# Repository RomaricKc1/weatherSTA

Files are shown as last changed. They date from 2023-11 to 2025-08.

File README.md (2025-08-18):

# weatherSTA

# Weather Station and Clock with ESP32, BME280, SCD40 and OpenWeather API

This project is a weather station and clock, that runs on an `ESP32` using the `Arduino` framework and `FreeRTOS`. It measures and displays indoor environmental data in real-time, as well as outdoor weather data through the OpenWeather API.

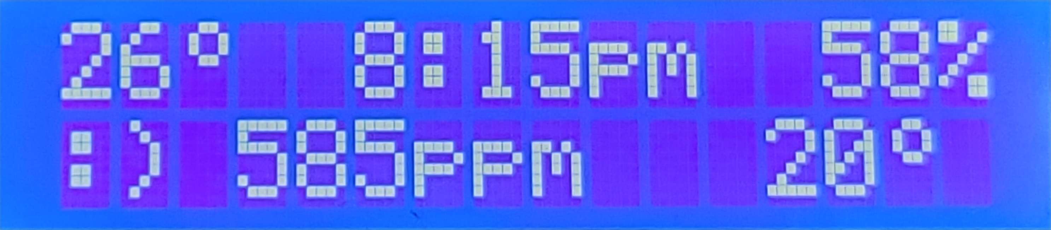
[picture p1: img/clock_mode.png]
Clock mode


Dashboard example            |  Enclosure: Box | Enclosure: Lid
:-------------------------:|:-------------------------:|-------------------------:
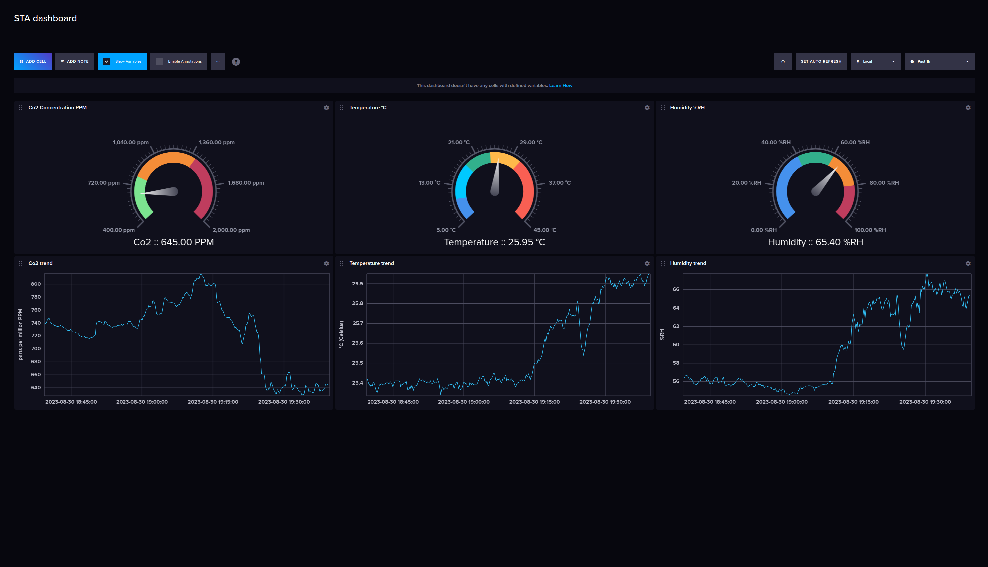
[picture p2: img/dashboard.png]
Dashboard
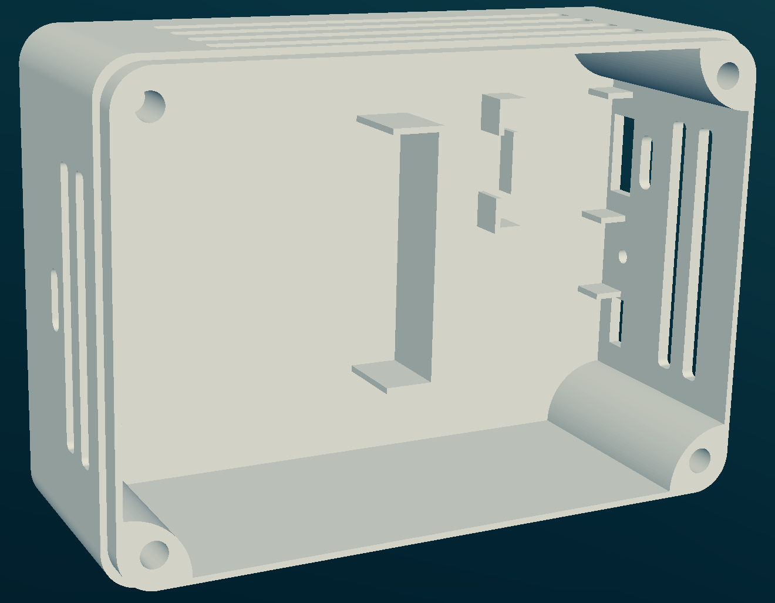
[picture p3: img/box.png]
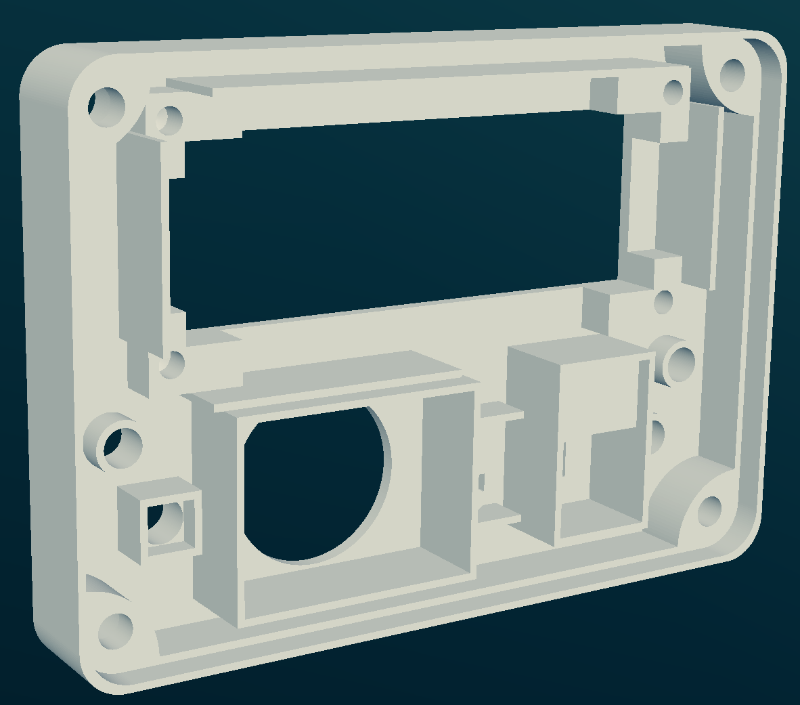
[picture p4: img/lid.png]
  |   |  

<details>
<summary>Click to view the results displayed on the browser</summary>

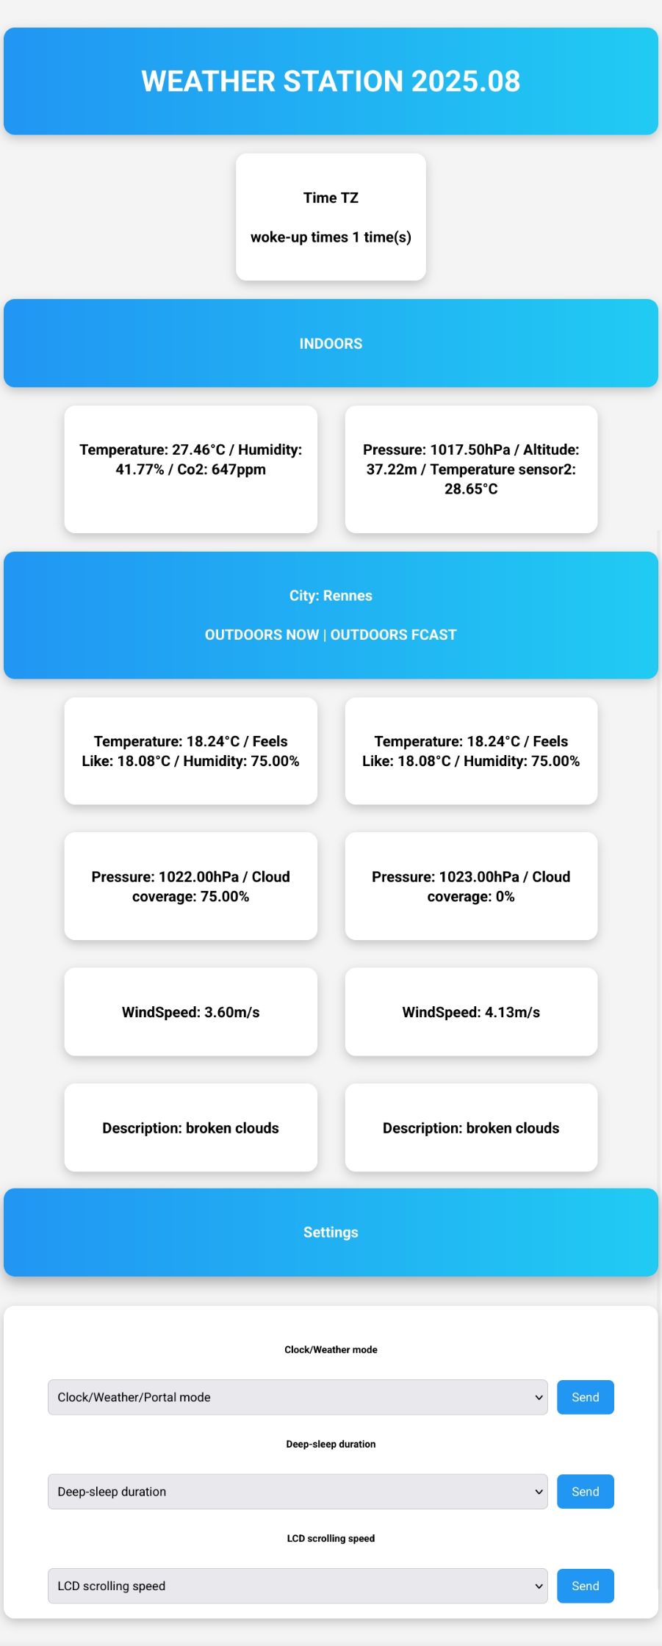
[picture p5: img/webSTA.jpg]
webview


</details>

## Getting Started

> [!IMPORTANT]
> Download the already compiled firmware(`.hex, .bin, the partitions.bin and the spiffs`) from the `release page` and flash it to your `ESP32`. 
>
> Alternatively, you can build it from source by yourself.
>
> Boot the ESP and connect to the created WIFI network `"STA esp"`. The default password (`P@55w0rd`) is in the `configs.hpp` header file.
>
> Connect the ESP to the desired WIFI network in the wifimanager portal, then reboot to validate the access point. After that, you'll have to reconnect to the portal in the `setup` page, to enter the required configuration parameters. After that, the esp will reboot and you'll be all set. `Voilà`.

### Build Steps
```bash
# build and upload file system
platformio run --target uploadfs -e esp32dev
# build and upload firmware
platformio run --target upload -e esp32dev 
```

> [!NOTE]
> You can access the web server via `http://weather_sta.local` or by looking up the ip addressed assigned to the esp32 and going to `http://[ip_addr]`
>
> Many of the configuration options can be modified in the `configs.hpp`. Such as timing related, `ntp` servers and `timezone` etc.
>
> Almost the essentials configs can be done dynamically. After the firmware has been built, you can use the wifi manager portal to set the value as you wish.

### OTA Updates
You can upload a new firmware through `WiFiManager` at `http://[ip_addr]/update`. You can enable the `on-demand` portal using the physical `button` connected to the `pin27`, and navigate to `Chg WLAN` and set it to `Yes`.

## Features

**Two Operating Modes**: The system operates in two distinct modes - Clock Mode (default) and Station Mode.
   - **Clock Mode**: Displays indoor environment data (temperature, humidity, CO2 concentration) and the current time. The time is fetched using the NTP protocol.
   - **Station Mode**: Cycles through displaying indoor data, current outdoor data from the OpenWeather API, and outdoor forecast data. After cycling, the system goes idle for a configurable duration, shuts down, and then restarts.

> [!NOTE]
> The system uses a PIR sensor to detect human presence and manage the LCD backlight, reducing power consumption. The PIR sensor's duration is configurable.
>
> The system connects to WiFi using WiFiManager with local webserver
>
> Three LEDs indicating rain (from current weather data), hot (indoor temperature above 24°C), and cold conditions.
>
> A buzzer provides hourly chimes, with a long chime at 12 am and pm. It stops making noise from 2 am to 6 am.
>
> InfluxDB integration: pushes every 10s data that can be visualized using the provided dashboard (see influx_dashboard)
> STL files for a 3D printable enclosure.

## Main Sensors

1. BME280 Sensor: Used for measuring indoor temperature, humidity, and pressure.
2. SCD40 Sensor: Used for measuring indoor CO2 concentration.

## Libraries Used

More in `platformio.ini` file.

## Wirings
| Module | Connection |
|---|---|
| LCD 16x2 |  I2C  |
| BME280 |  I2C  |
| SCD40  |  I2C  |
| LED cold  |  D19  |
| LED hot |  D18  |
| LED rain  |  D5  |
| BTN  |  D27  |
| Buzzer  |  D2  |
| PIR  |  D17  |

## MISC
WIFI connection lost: `LED cold` and `LED hot` blink for 5s.

### Config Menu: 
`CLOCK mode {ON/OFF}`, `LCD Speed 250-500(ms)`, `Sleep T 30-60(s)`, `Deep-sleep T 15-60(mins)`,`Am/PM {AM/PM}`, `Chg WLAN {ON/OFF}`

### TODO
- [ ] Outdoors air quality metrics
- [ ] Add target for other esp version

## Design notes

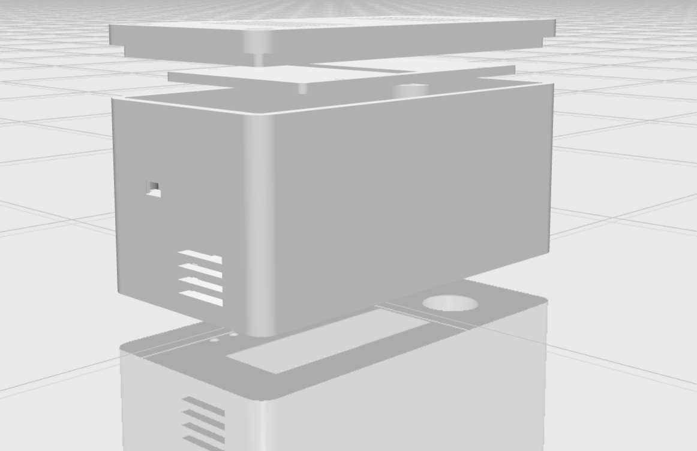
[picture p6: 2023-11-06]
img/enclosure.png

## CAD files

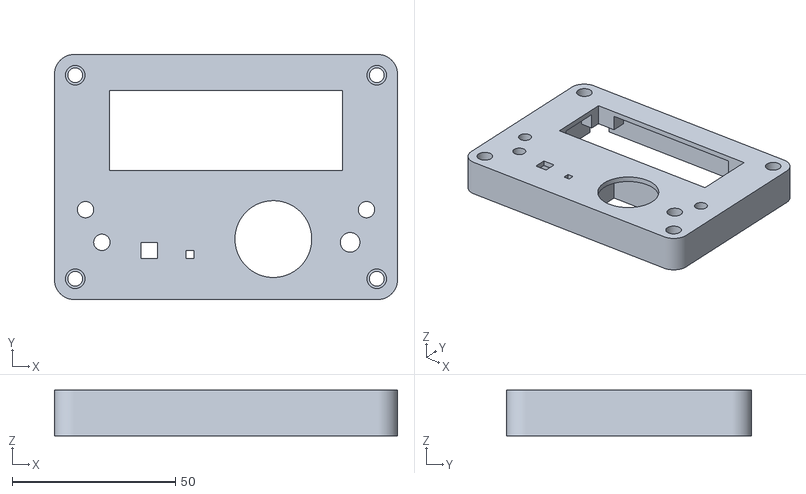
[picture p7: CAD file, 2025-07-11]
STL_file/Lid.stl
105.0 x 75.0 x 14.0

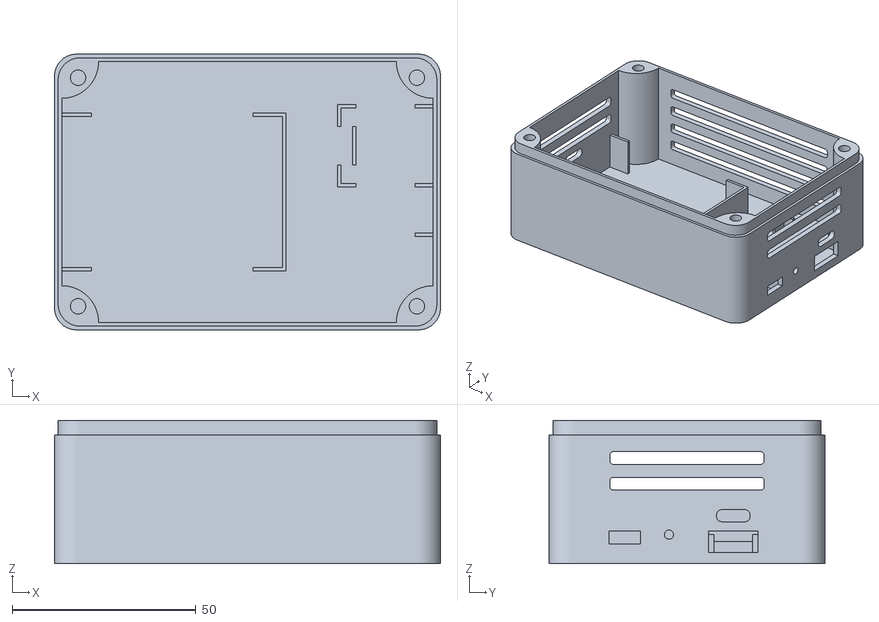
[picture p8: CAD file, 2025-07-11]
STL_file/Box.stl
105.0 x 75.0 x 39.0

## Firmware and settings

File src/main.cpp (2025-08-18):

#include "commons.hpp"
#include "graphics.hpp"
#include "influx_db.hpp"
#include "init.hpp"
#include "sensors.hpp"
#include "weather_api.hpp"
#include "web_server.hpp"
#include "wm.hpp"

void setup() {
    N_Common::initRtc();
    N_WeatherAPI::initApiStr();

    N_Graphics::initLcd();
    N_InfluxDb::initInfluxStr();
    N_Sensors::initSensors(); // bme, scd40
    N_WebServer::initServer();

    N_WM::initWM();

    if (!N_Sensors::scd40 or !N_Sensors::bme or !N_WebServer::server or
        !N_Graphics::lcd) {
        assert("abort");
    }

    N_Init::setupBase();
}

void loop() {
    // put your main code here, to run repeatedly:
    // no lol
    vTaskDelete(nullptr);
}

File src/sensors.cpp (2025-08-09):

#include "sensors.hpp"

namespace N_Sensors {
    std::unique_ptr<Adafruit_BME280> bme;
    std::unique_ptr<SensirionI2cScd4x> scd40;

    TaskHandle_t xSensor = nullptr;

    void initSensors() {
        try {
            bme   = std::make_unique<Adafruit_BME280>();
            scd40 = std::make_unique<SensirionI2cScd4x>();
        } catch (const std::exception &e) {
            assert("abort");
        }
    }

    void vTaskSensors(void * /*pvParameters*/) {
        const char *pcTaskName = "vTaskSensors";

        S_DataOffline data;
        S_InfluxTaskRunnerArgs influx_runner_args{};

        N_InfluxDb::getServerState(influx_runner_args.is_server_up,
                                   pcTaskName); // try connecting to the server

        // await scd calibration, do not clear on exit
        xEventGroupWaitBits(N_Common::handler_event, (1U << SCD_CAL_DONE),
                            pdFALSE, pdFALSE, portMAX_DELAY);
        if ((N_Common::debug_msk & (1U << DEBUG_SENSORS)) != 0U) {
            N_Helpers::idAndMsg(
                {.id = pcTaskName, .word = "SCD41 calibration terminated"});
        }

        N_InfluxDb::getServerState(influx_runner_args.is_server_up,
                                   pcTaskName); // try connecting to the server
        for (;;) {
            vSensorsPushData(data, pcTaskName);

            // Regularly check if the influx db server is up? default: T = 5
            // mins
            if (!influx_runner_args.is_server_up and
                (xTaskGetTickCount() - influx_runner_args.ticktime >
                 T_CHECK_SERVER_STATUS_MS)) {
                influx_runner_args.ticktime = xTaskGetTickCount();
                N_InfluxDb::getServerState(
                    influx_runner_args.is_server_up,
                    pcTaskName); // try connecting to the server
            }

            //  And start sending the sensor data to the server if it's up
            vSensorsInfluxRunner(influx_runner_args, pcTaskName);

            vTaskDelay(pdMS_TO_TICKS(T_SENSORS_MS));
        }
    }

    void vSensorsPushData(S_DataOffline &data, const char *pcTaskName) {
        bool data_ready{false};
        uint16_t error{};

        std::array<char, SCD_ERR_MSG_LEN> errorMessage{};

        error = N_Sensors::scd40->getDataReadyStatus(data_ready);
        if (data_ready and
            xSemaphoreTake(N_Common::xI2C, portMAX_DELAY) == pdPASS) {
            uint16_t co2_val{};
            float temp_val{};
            float humi_val{};
            error =
                N_Sensors::scd40->readMeasurement(co2_val, temp_val, humi_val);

            data.co2   = co2_val;
            data.temp2 = temp_val;
            data.humi  = humi_val;

            // humi of bme
            data.temp     = N_Sensors::bme->readTemperature() - TEMP_OFFSET;
            data.humi_bme = N_Sensors::bme->readHumidity();
            data.pressure = N_Sensors::bme->readPressure() / 100.0F;
            data.altitude = N_Sensors::bme->readAltitude(
                N_WeatherAPI::SEALEVELPRESSURE_HPA_2);

            xSemaphoreGive(N_Common::xI2C);
        }

        if (error == 0 && data.co2 != 0) {
            // send it to the queue
            xQueueOverwrite(N_Common::xQueueOffline, &data);
        } else if ((N_Common::debug_msk & (1U << DEBUG_SENSORS)) != 0U) {
            errorToString(error, errorMessage.data(), SCD_ERR_MSG_LEN);
            N_Helpers::idAndMsg(
                {.id   = pcTaskName,
                 .word = "SCD bad measurement: " +
                         static_cast<String>(errorMessage.data())});
        }
    }

    void pirLogic(bool &pir_state, bool &last_pir, S_BlMgmt &that_mgmt,
                  TickType_t &last_detected_pir, const bool valid_clk) {
        if (!valid_clk) {
            return;
        }

        // pir needs about 5s to re-arm the system, how to counter this?
        ((digitalRead(PIR_BL)) != 0U) ? pir_state = HIGH : pir_state = LOW;
        if ((pir_state != last_pir) && pir_state &&
            (xSemaphoreTake(N_Common::xLCDAccess, T_WAIT_PIR_I2C_LOCK_MS) ==
             pdPASS)) {
            // this helps counter the fact of writing true true or false
            // false repeatedly also, only write true, the false will be
            // taken care
            if (xSemaphoreTake(N_Common::xI2C, T_WAIT_PIR_I2C_LOCK_MS) ==
                pdPASS) {
                N_Graphics::lcd->backlight();
                xSemaphoreGive(N_Common::xI2C);

                that_mgmt.turned_on  = true;
                that_mgmt.extended_T = 0;
            }
            xSemaphoreGive(N_Common::xLCDAccess);

            // keep it lit until the end of (detection + 5s) time
        }
        last_pir = pir_state;

        if (last_pir) {
            last_detected_pir =
                xTaskGetTickCount(); // record last time it stopped
            return;
        }

        // aka stopped detecting, it need 5s to restart reading new state
        // turn on the lit and keep it for 5s
        if (((xTaskGetTickCount() - last_detected_pir) >
             T_PIR_COUNTER_DELAY_MS) and
            xSemaphoreTake(N_Common::xLCDAccess, T_WAIT_PIR_I2C_LOCK_MS) ==
                pdPASS) // added 1 s to it
        {
            if (that_mgmt.turned_on and
                xSemaphoreTake(N_Common::xI2C, T_WAIT_PIR_I2C_LOCK_MS) ==
                    pdPASS) {
                if (!that_mgmt.extended_bl or
                    that_mgmt.extended_T > pdMS_TO_TICKS(that_mgmt.up_to_T)) {
                    N_Graphics::lcd->noBacklight();

                    that_mgmt.extended_T = 0;
                    that_mgmt.turned_on  = false;
                }
                that_mgmt.extended_T++;
                xSemaphoreGive(N_Common::xI2C);
            }
            xSemaphoreGive(N_Common::xLCDAccess);
        }
    }

    auto bmeSetup(S_DataOffline &data) -> bool {
        // BME CONFIG weather mode
        if (!N_Sensors::bme->begin(BME_I2C_ADDR, &Wire)) {
            if ((N_Common::debug_msk & (1U << DEBUG_SENSORS)) != 0U) {
                const char *pcTaskName = "bmeSetup";
                N_Helpers::idAndMsg(
                    {.id   = pcTaskName,
                     .word = "Error reading from bme sensor, rebooting"});
            }
            return true;
        }

        // humi of bme
        data.temp = N_Sensors::bme->readTemperature() - TEMP_OFFSET;
        data.humi = N_Sensors::bme->readHumidity();
        data.pressure =
            N_Sensors::bme->readPressure() / PRESSURE_CALC_100_FLOAT;
        data.altitude =
            N_Sensors::bme->readAltitude(N_WeatherAPI::SEALEVELPRESSURE_HPA_2);

        // co2
        data.co2 = INVALID_CO2_VAL;

        return false;
    }

    auto scdSetup() -> bool {
        uint16_t error{};
        std::array<char, SCD_ERR_MSG_LEN> errorMessage{};

        Wire.begin();
        N_Sensors::scd40->begin(Wire, SCD41_I2C_ADDR_62);
        const char *pcTaskName = "scdSetup";
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

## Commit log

2025-07-11 feat: user configurable influx db and NTP info + better STL files
    - specify one own's influx config through the wifimanager portal
    - same for the NTP servers and timezone info
    - added an extended LCD backlight at night time (serves as a room lamp)
    - more reasonable STL file box and lid separated.
    [Box.stl, Lid.stl]
2025-08-01 refactoring, and ci setup
    - deps upgrade
    - better json handling
    - fix influxdb writer add separate task for non-blocking sensors
    readings
    - cppcheck and clangtidy checks and test runs
    - export the firmware as build artifact
    - fix high LCD refreses which was draining the battery pretty fast
    - various bug fixes
    - project format
    - remove unused cred.h file (all credentials are put dyn using
    wifimanager)
    [main.cpp]
2025-08-09 full refactor, for `blazing` 💥 fast system
    - organized the code
    - removed w3.css and jquery to reduce storage usage
    - improved the frontend ui, reduced load times
    - massive improvment with reduced memory usage
    - fix to the display over-refreshing
    - actual safe cpp, no more `c` to c here "`c->see, you get it? haha`" :)
    [graphics.cpp]
2025-08-18 style(fmt): get rid of 'CRLF line terminators' [ci skip]
    - update readme with firmware OTA update
    [main.cpp]
